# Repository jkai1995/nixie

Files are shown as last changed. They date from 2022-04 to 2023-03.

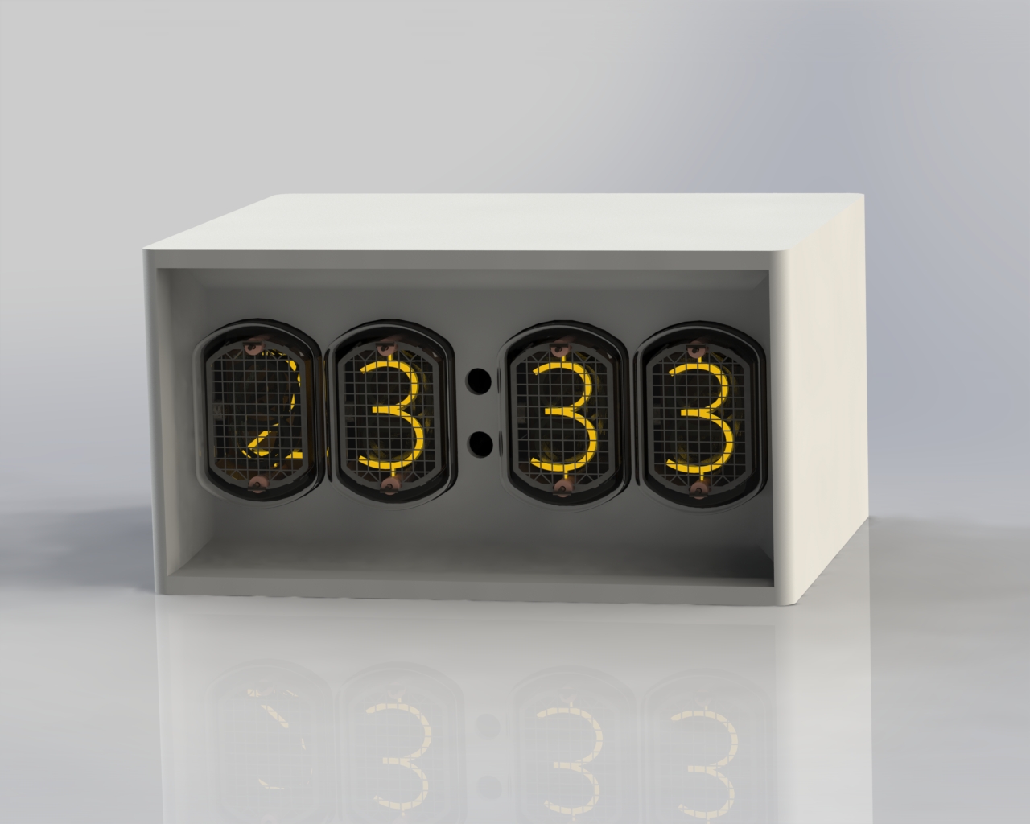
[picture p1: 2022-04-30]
3d/preview2.JPG

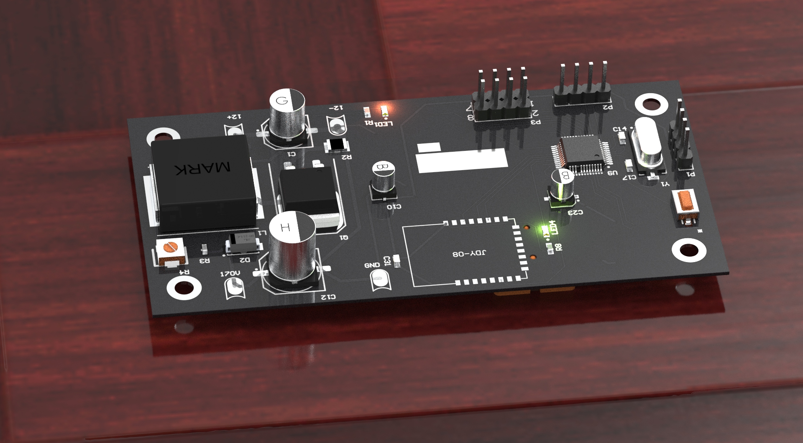
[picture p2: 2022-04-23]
3d/pcb-logical1.jpg

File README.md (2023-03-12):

# nixie




## 硬件结构
IN-12的管子,串联74HC595驱动

12-170V升压用MAX1771

stm32+DS3231

蓝牙BLE用于控制

## 软件
FreeRTOS

letter-shell调试和控制，非常方便 https://github.com/NevermindZZT/letter-shell

### 软件结构


realtimeCtrl线程读写时钟芯片ds3231的数据，并通过6片串联的串入并出移位寄存器74HC595驱动辉光管

shell线程通过JDY08蓝牙模块或者直连的串口交互，支持多种命令

## 上位机

## 调试问题

### 升压电路
一开始用的一体成型电感只有空载不会发热，稍微加一点负载就会严重温升

换了更大电流的铁硅铝磁环电感可以不发热

参数选择应该是绰绰有余的，

分析应该是买到了假的芯片，输出并不是手册上说明的PFM，而是固定频率的高频(远低于手册的频率)可调频率的低频 “与” 形成的信号
而买来的max1771模块的输出是和手册一致的高频PFM

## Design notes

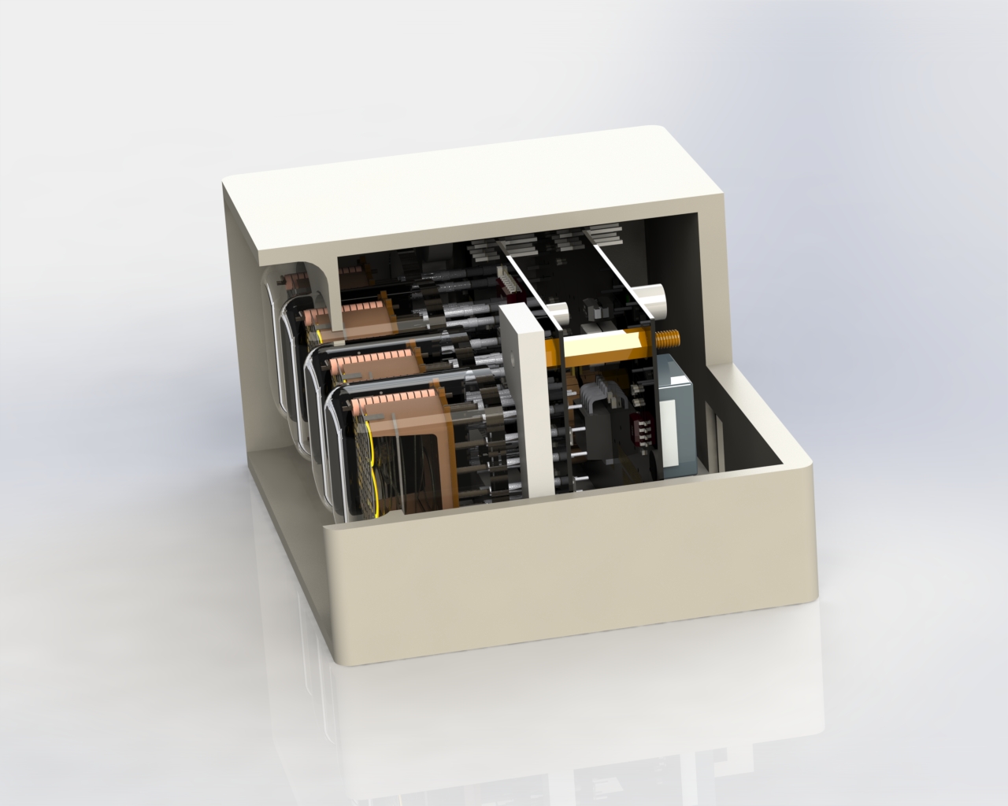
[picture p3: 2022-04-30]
3d/preview3.JPG

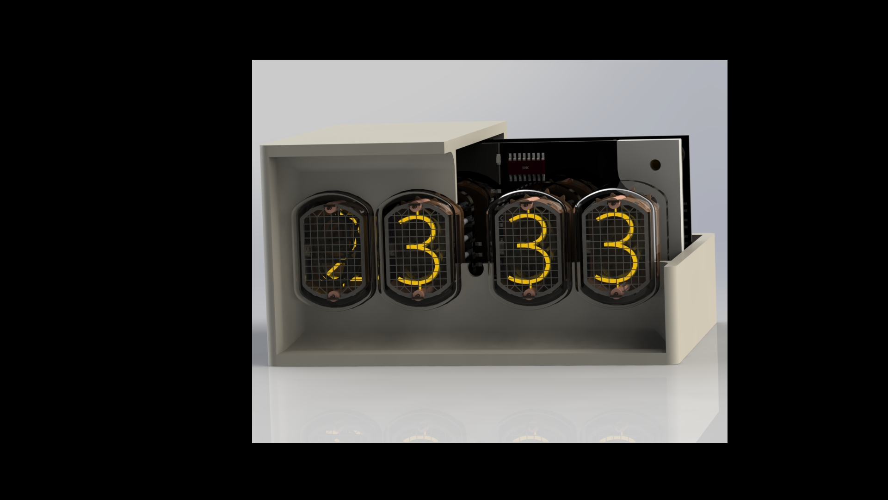
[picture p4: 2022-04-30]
3d/preview.JPG

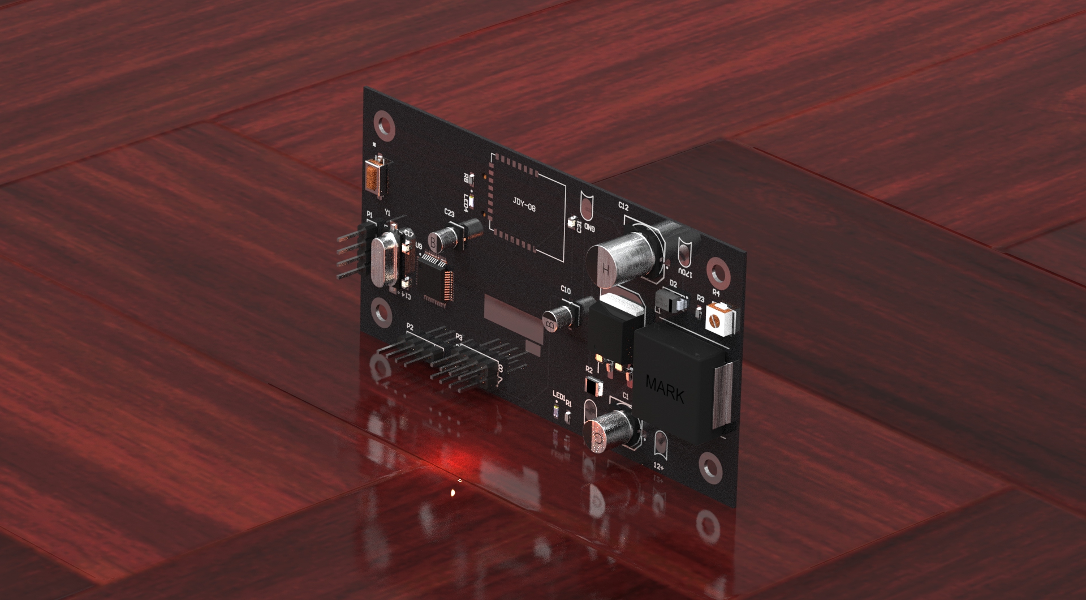
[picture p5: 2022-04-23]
3d/pcb-logical2.jpg

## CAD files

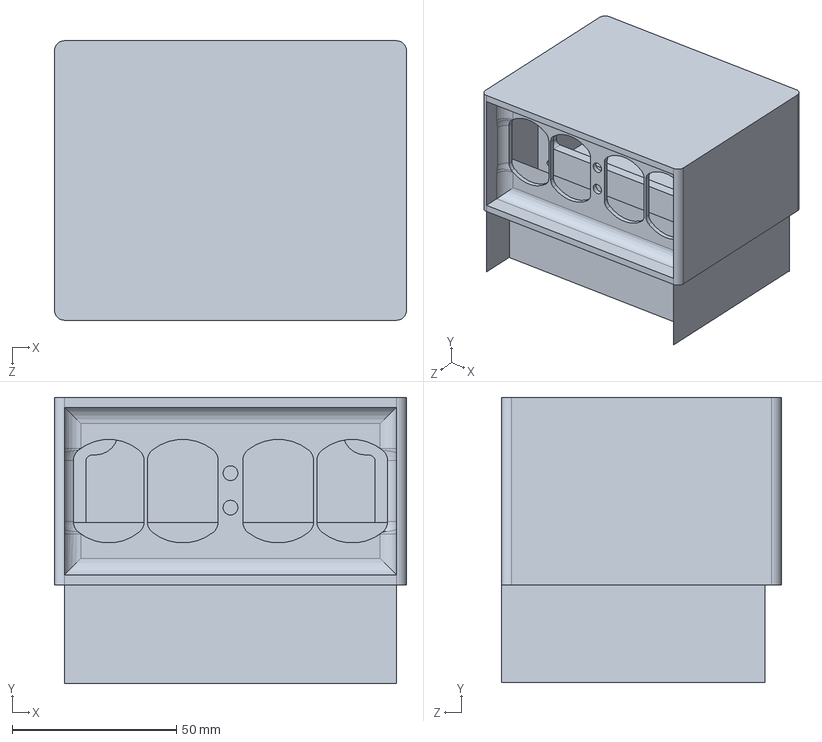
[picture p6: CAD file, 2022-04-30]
3d/零件1.SLDPRT
107.0 x 87.0 x 85.0 mm

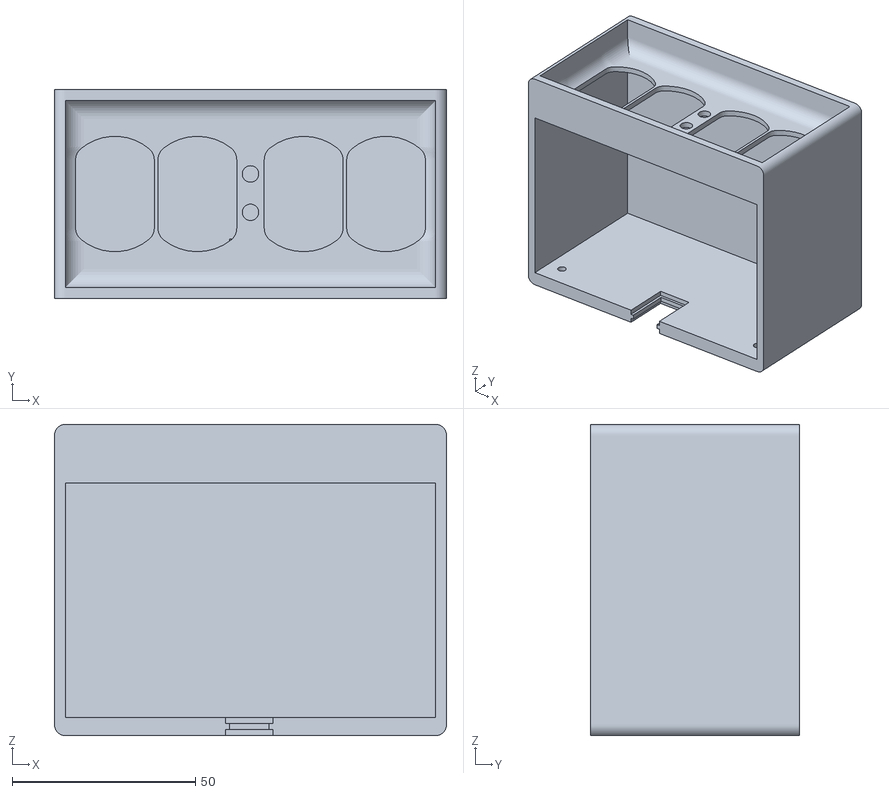
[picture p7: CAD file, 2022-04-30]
3d/上盖.STL
107.0 x 57.0 x 85.0

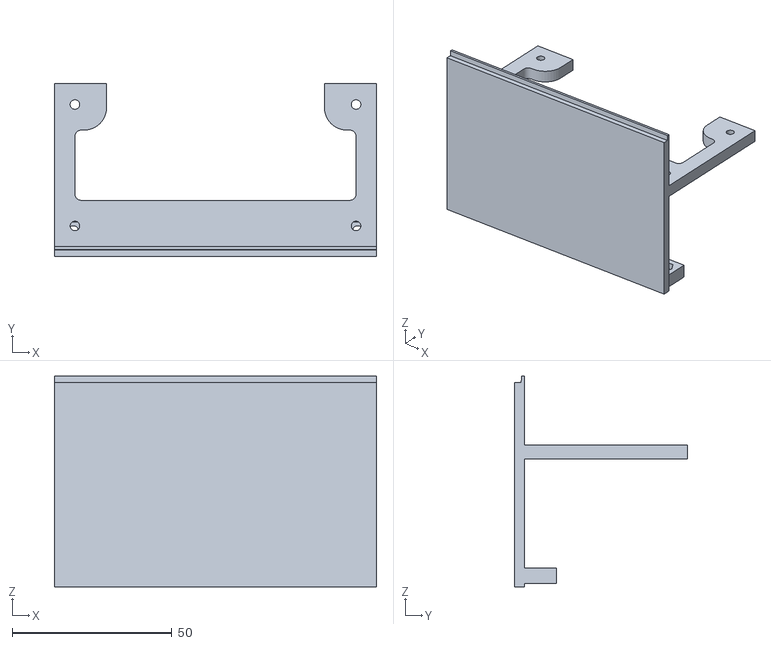
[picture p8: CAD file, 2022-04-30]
3d/底座.STL
100.8 x 54.0 x 66.0

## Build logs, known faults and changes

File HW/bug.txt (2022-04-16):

辉光管封装反了
螺丝孔被盖油 需要改成焊盘 不能用过孔
没有预留接口
boots电路默认是开启的，最好硬件配置成可以默认开也可以默认关
双排的丝印错位

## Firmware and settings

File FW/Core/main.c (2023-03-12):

#include "stm32f10x.h"
#include "powerCtrl.h"
#include "shellPort.h"
#include "misc.h"
#include "FreeRTOS.h"
#include "task.h"
#include "realtimeCtrl.h"

void createTasks(void *pvParameters )
{
    powerCtrlInit();
    createShellTask();
    createRealtimeTask();
    vTaskSuspend(NULL);
}


int main (void)
{
    /*设置优先级分组*/
    NVIC_PriorityGroupConfig(NVIC_PriorityGroup_4);

    TaskHandle_t xHandle;

    xTaskCreate(createTasks,
                "createTasks",
                64,
                NULL,
                1,
                &xHandle);
    /*启动任务调度器，任务开始执行*/
    vTaskStartScheduler();


    for(;;);
}

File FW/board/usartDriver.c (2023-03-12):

#include "stm32f10x_gpio.h"
#include "stm32f10x_usart.h"
#include "misc.h"
#include "stm32f10x_rcc.h"
#include "stm32f10x_dma.h"

#include "usartDriver.h"

#define FALSE                                  ( 0 )
#define TRUE                                   ( 1 )


#define DMABufferNum 2
typedef struct
{
    u8* buffer[DMABufferNum];
    u32 size;
    u32 currIdx;
}DMABuffer_t;


#define USART1BaudRate 115200
#define USART2BaudRate 115200

static DMABuffer_t        m_USART1DMABuffer;
static DMABuffer_t        m_USART2DMABuffer;
static pfnOnReceiveData OnUSART2ReceiveData = NULL;
static pfnOnReceiveData OnUSART1ReceiveData = NULL;

void DMA_SetMemoryBuffer(DMA_Channel_TypeDef* DMAy_Channelx,DMABuffer_t *pBuff)
{
    DMAy_Channelx->CMAR = (u32)pBuff->buffer[pBuff->currIdx];
    DMAy_Channelx->CNDTR = pBuff->size;
}

void USART2_Init(pfnOnReceiveData pfn,UsartReceiveBuffer_t *pBuff)
{
    GPIO_InitTypeDef GPIO_InitStrue;
    USART_InitTypeDef USART_InitStrue;
    NVIC_InitTypeDef NVIC_InitStrue;
    DMA_InitTypeDef DMA_InitStructure;

    m_USART2DMABuffer.size = pBuff->size / DMABufferNum;
    m_USART2DMABuffer.currIdx = 0;
    for (u32 i = 0; i < DMABufferNum; i++)
    {
        m_USART2DMABuffer.buffer[i] = &(pBuff->addr[m_USART2DMABuffer.size * i]);
    }
    // 外设使能时钟
    RCC_APB2PeriphClockCmd(RCC_APB2Periph_GPIOA,ENABLE);
    RCC_APB1PeriphClockCmd(RCC_APB1Periph_USART2,ENABLE);
    RCC_AHBPeriphClockCmd(RCC_AHBPeriph_DMA1, ENABLE);

    USART_DeInit(USART2);  //复位串口2 -> 可以没有

    // 初始化 串口对应IO口    TX-PA2    RX-PA3
    GPIO_InitStrue.GPIO_Mode=GPIO_Mode_AF_PP;
    GPIO_InitStrue.GPIO_Pin=GPIO_Pin_2;
    GPIO_InitStrue.GPIO_Speed=GPIO_Speed_50MHz;
    GPIO_Init(GPIOA,&GPIO_InitStrue);
    
    GPIO_InitStrue.GPIO_Mode=GPIO_Mode_IN_FLOATING;
    GPIO_InitStrue.GPIO_Pin=GPIO_Pin_3;
    GPIO_Init(GPIOA,&GPIO_InitStrue);

    // 初始化 串口模式状态
    USART_InitStrue.USART_BaudRate=USART2BaudRate; // 波特率
    USART_InitStrue.USART_HardwareFlowControl=USART_HardwareFlowControl_None; // 硬件流控制
    USART_InitStrue.USART_Mode=USART_Mode_Tx|USART_Mode_Rx; // 发送 接收 模式都使用
    USART_InitStrue.USART_Parity=USART_Parity_No; // 没有奇偶校验
    USART_InitStrue.USART_StopBits=USART_StopBits_1; // 一位停止位
    USART_InitStrue.USART_WordLength=USART_WordLength_8b; // 每次发送数据宽度为8位
    USART_Init(USART2,&USART_InitStrue);
    
    
    // 初始化 中断优先级
    NVIC_InitStrue.NVIC_IRQChannel=USART2_IRQn;
    NVIC_InitStrue.NVIC_IRQChannelCmd=ENABLE;
    NVIC_InitStrue.NVIC_IRQChannelPreemptionPriority=1;
    NVIC_InitStrue.NVIC_IRQChannelSubPriority=1;
    NVIC_Init(&NVIC_InitStrue);

    DMA_Cmd(DMA1_Channel6,DISABLE);
    DMA_DeInit(DMA1_Channel6);

        //外设地址
    DMA_InitStructure.DMA_PeripheralBaseAddr = (u32)(&USART2->DR);
    //内存地址
    DMA_InitStructure.DMA_MemoryBaseAddr = (u32)m_USART2DMABuffer.buffer[m_USART2DMABuffer.currIdx]; 
    //dma传输方向单向
    DMA_InitStructure.DMA_DIR = DMA_DIR_PeripheralSRC; 
    //设置DMA在传输时缓冲区的长度
    DMA_InitStructure.DMA_BufferSize = m_USART2DMABuffer.size;
    //设置DMA的外设递增模式，一个外设
    DMA_InitStructure.DMA_PeripheralInc = DMA_PeripheralInc_Disable;
    //设置DMA的内存递增模式
    DMA_InitStructure.DMA_MemoryInc = DMA_MemoryInc_Enable;
    //外设数据字长
    DMA_InitStructure.DMA_PeripheralDataSize = DMA_PeripheralDataSize_Byte;
    //内存数据字长
    DMA_InitStructure.DMA_MemoryDataSize = DMA_PeripheralDataSize_Byte;
    //设置DMA的传输模式
    DMA_InitStructure.DMA_Mode = DMA_Mode_Normal;
    //设置DMA的优先级别
    DMA_InitStructure.DMA_Priority = DMA_Priority_High;
    //设置DMA的2个memory中的变量互相访问
    DMA_InitStructure.DMA_M2M = DMA_M2M_Disable;
    DMA_Init(DMA1_Channel6,&DMA_InitStructure);


    USART_ITConfig(USART2,USART_IT_IDLE, ENABLE);
    USART_ClearFlag(USART1, USART_FLAG_IDLE);
    USART_DMACmd(USART2,USART_DMAReq_Rx,ENABLE); //DMA接收
    USART_DMACmd(USART2,USART_DMAReq_Tx,ENABLE);//DMA发送

    DMA_ClearFlag(DMA1_FLAG_TC6);//清除DMA所以标志
    DMA_ITConfig(DMA1_Channel6,DMA_IT_TE,ENABLE);


    USART_Cmd(USART2,ENABLE);//使能串口
    DMA_Cmd(DMA1_Channel6,ENABLE);


    OnUSART2ReceiveData = pfn;
}



void USART2_IRQHandler(void) // 串口2中断服务函数
{
    u8 res;
    if(USART_GetITStatus(USART2,USART_IT_RXNE)) // 中断标志
    {
        //while (USART_GetFlagStatus(USART2,USART_FLAG_RXNE))
        {
            res= USART_ReceiveData(USART2);  // 串口2 接收
            if (OnUSART2ReceiveData != NULL)
            {
                OnUSART2ReceiveData(&res,1,TRUE);
            }
        }
    }
    else if (USART_GetITStatus(USART2,USART_IT_IDLE))
    {
        DMA_Cmd(DMA1_Channel6,DISABLE);
        DMA_ClearFlag(DMA1_FLAG_TC6);
        USART2->SR;
        USART2->DR;//IDLE中断需要先读SR再读DR才能清掉
        //总计数减去未传输的数据个数，得到已经接收的数据个数
        u32 size = m_USART2DMABuffer.size - DMA_GetCurrDataCounter(DMA1_Channel6);
        u8* data = m_USART2DMABuffer.buffer[m_USART2DMABuffer.currIdx];

        if (OnUSART2ReceiveData != NULL)
        {
            OnUSART2ReceiveData(data,size,TRUE);
        }

        m_USART2DMABuffer.currIdx = (m_USART2DMABuffer.currIdx + 1) % DMABufferNum;
        DMA_SetMemoryBuffer(DMA1_Channel6,&m_USART2DMABuffer);
        DMA_Cmd(DMA1_Channel6,ENABLE);
        //USART_ClearITPendingBit(USART2, USART_IT_IDLE);
    }
}


void USART2_WriteDMA(uint8_t *Data, uint32_t len)
{
    DMA_InitTypeDef DMA_InitStruct;
    DMA_Cmd(DMA1_Channel7,DISABLE);
    DMA_InitStruct.DMA_PeripheralBaseAddr = (u32)(&USART2->DR);
    DMA_InitStruct.DMA_MemoryBaseAddr = (u32)Data;
    DMA_InitStruct.DMA_DIR = DMA_DIR_PeripheralDST;
    DMA_InitStruct.DMA_BufferSize = len;
    DMA_InitStruct.DMA_PeripheralInc = DMA_PeripheralInc_Disable;
    DMA_InitStruct.DMA_MemoryInc = DMA_MemoryInc_Enable;
    DMA_InitStruct.DMA_PeripheralDataSize = DMA_PeripheralDataSize_Byte;
    DMA_InitStruct.DMA_MemoryDataSize = DMA_PeripheralDataSize_Byte;
    DMA_InitStruct.DMA_Mode = DMA_Mode_Normal;
    DMA_InitStruct.DMA_Priority = DMA_Priority_VeryHigh;
    DMA_InitStruct.DMA_M2M = DMA_M2M_Disable;
    DMA_Init(DMA1_Channel7,&DMA_InitStruct);
    DMA_ClearFlag(DMA1_FLAG_TC7);//传输完成标志位
    DMA_Cmd(DMA1_Channel7,ENABLE);
    while(!DMA_GetFlagStatus(DMA1_FLAG_TC7))
    {}
    DMA_ClearFlag(DMA1_FLAG_TC7);

}

s16 USART2_Write(char *ch, u16 num)
{

    for (int i = 0; i < num; i++)
    {
        while (USART_GetFlagStatus(USART2,USART_FLAG_TXE) == RESET);
        USART_SendData(USART2,ch[i]);
    }
    return 0;

    //USART2_WriteDMA(ch,num);
    //return 0;
}
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

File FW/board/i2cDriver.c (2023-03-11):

#include "stm32f10x_gpio.h"
#include "misc.h"
#include "stm32f10x_rcc.h"
#include "stm32f10x_gpio.h"
#include "stm32f10x_i2c.h"
#include "i2cDriver.h"

enum
{
    SCL,//PA11 连接后高电平，未连接低电平
    SDA,//PA8 连接以后按下断开连接
    PinMax,
};

static GPIO_TypeDef* m_btGpiox[PinMax] =
{
    GPIOB,
    GPIOB,
};
static u16 m_btPinx[PinMax] =
{
    GPIO_Pin_6,
    GPIO_Pin_7,
};

void I2C1_Init(void)
{
    GPIO_InitTypeDef  GPIO_InitStructure;
    I2C_InitTypeDef I2C_InitStruct;
    RCC_APB1PeriphClockCmd(RCC_APB1Periph_I2C1,ENABLE);
    RCC_APB2PeriphClockCmd(RCC_APB2Periph_GPIOB, ENABLE);

    GPIO_InitStructure.GPIO_Pin =  m_btPinx[SCL];
    GPIO_InitStructure.GPIO_Speed = GPIO_Speed_50MHz;
    GPIO_InitStructure.GPIO_Mode = GPIO_Mode_AF_OD; 
    GPIO_Init(m_btGpiox[SCL], &GPIO_InitStructure);
    GPIO_InitStructure.GPIO_Pin =  m_btPinx[SDA];
    GPIO_InitStructure.GPIO_Speed = GPIO_Speed_50MHz;
    GPIO_InitStructure.GPIO_Mode = GPIO_Mode_AF_OD;
    GPIO_Init(m_btGpiox[SDA], &GPIO_InitStructure);


    I2C_InitStruct.I2C_Ack=I2C_Ack_Enable;
    I2C_InitStruct.I2C_AcknowledgedAddress=I2C_AcknowledgedAddress_7bit;
    I2C_InitStruct.I2C_ClockSpeed=400000;
    I2C_InitStruct.I2C_DutyCycle=I2C_DutyCycle_2;
    I2C_InitStruct.I2C_Mode=I2C_Mode_I2C;
    I2C_InitStruct.I2C_OwnAddress1=0x55;
    I2C_Init(I2C1,&I2C_InitStruct);

    I2C_Cmd(I2C1,ENABLE);
}


/*写入一个字节*/
void IIC_WriteBytes(u8 slaveAddr,u8* data,u8 num)
{
    I2C_GenerateSTART(I2C1,ENABLE);
    while(!I2C_CheckEvent(I2C1,I2C_EVENT_MASTER_MODE_SELECT))//检测    EV5事件
    {
    }

    slaveAddr = (slaveAddr << 1);
    I2C_Send7bitAddress(I2C1,slaveAddr,I2C_Direction_Transmitter);
    while(!I2C_CheckEvent(I2C1,I2C_EVENT_MASTER_TRANSMITTER_MODE_SELECTED))//检测EV6事件
    {
    }

    for (int i = 0; i < num; i++)
    {
        I2C_SendData(I2C1,data[i]);//发送操作的内存地址
        while(!I2C_CheckEvent(I2C1,I2C_EVENT_MASTER_BYTE_TRANSMITTED))//检测EV8事件
        {
        }
    }    
    I2C_GenerateSTOP(I2C1,ENABLE);//发送结束信号
    
}
 
/*读取一个字节*/
void IIC_ReadBytes(u8 slaveAddr,u8* data,u8 num)
{
    I2C_GenerateSTART(I2C1,ENABLE);
    while(!I2C_CheckEvent(I2C1,I2C_EVENT_MASTER_MODE_SELECT))
    {
    }

    slaveAddr = (slaveAddr << 1);
    I2C_Send7bitAddress(I2C1,slaveAddr,I2C_Direction_Receiver);
    while(!I2C_CheckEvent(I2C1,I2C_EVENT_MASTER_RECEIVER_MODE_SELECTED))
    {
    }
    for (int i = 0; i < num; i++)
    {
        if (i == (num - 1))
        {
            I2C_AcknowledgeConfig(I2C1,DISABLE);
        }
        else
        {
            I2C_AcknowledgeConfig(I2C1,ENABLE);
        }
     
        /* 检测 EV7 事件 */
        while(I2C_CheckEvent(I2C1,I2C_EVENT_MASTER_BYTE_RECEIVED) != SUCCESS )
        {
        }
      
      /* 读取接收数据 */
      data[i] = I2C_ReceiveData(I2C1);
    }
  /* 停止信号 */
  I2C_GenerateSTOP(I2C1,ENABLE);
}

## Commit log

2022-04-16 update pcb 3d model
2022-04-23 add logcial pcb rendring
2023-03-11 调整文件位置
2023-03-11 替换tab
2023-03-12 修改串口部分结构
